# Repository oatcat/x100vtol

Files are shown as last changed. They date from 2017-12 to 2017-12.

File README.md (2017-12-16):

# x100vtol
a 100mm 4-rotor small drone using brushed motors, 2s li-po battery, 60mm prop.
One piece PCB-as-chassic, onboard mosfet motor driver, GY-86 as IMU.
Uses taulabs software. Hardware compatible as DISOVERY F4.

## To make one:
Order the PCB from a fab house, buy the necessary parts, solder the PCB.
Connect a S.BUS reciever to the port and fix the reciever on the PCB.
Flash taulabs firmware using ST-LINK, configure the UAV.

## BOM

Apart from the PCB BOM, you will need to secure the motors onto the PCB.
The motor mount I used is bought on taobao.com. If you can't get one you can change the PCB to suit your motor mount.

A small FPV Camera with built in VTX is needed if FPV is desireable.

A ~550mAh 2S battery is needed, and you will need a strap to fix the battery.
There are 2 slots on the PCB you can use to strap the battery.

For proper takeoff and landing you will need some kind of landing gear.
Just glue a small piece of plastic under each motor mount will be fine.

To flash the STM32 you will need ST-Link. Either a standalone one or a builtin on the Discovery board will be fine.

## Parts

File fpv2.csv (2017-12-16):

Qty | Value | Device | Package | Parts | Description | PROD_ID | VALUE
1 | 2PT_GND_TIE | 2PT_GND_TIE | 2PT_GND_TIE | SUPPLY1 | Dual Ground Supply
16 | 100n | C-EUC0603 | C0603 | C1, C2, C3, C4, C5, C6, C7, C8, C12, C13, C17, C19, C23, C24, C25, C26 | CAPACITOR, European symbol
2 | 20p | C-EUC0603 | C0603 | C21, C22 | CAPACITOR, European symbol
1 | 470pF | C-EUC0603 | C0603 | C20 | CAPACITOR, European symbol
2 | 2.2u | C-EUC1206 | C1206 | C14, C15 | CAPACITOR, European symbol
2 | 1u | CPOL-EUA/3216-18R | A/3216-18R | C10, C11 | POLARIZED CAPACITOR, European symbol
2 | 100u | CPOL-EUSMCB | SMC_B | C16, C18 | POLARIZED CAPACITOR, European symbol
1 | 8M | CRYSTALSMD-5X3.2-2PAD | CRYSTAL-SMD-5X3.2-2PAD | Y1 | Crystals (Generic)
4 | SS14 | DIODE-DO214AC | DO214AC | D5, D6, D7, D8 | DIODE
1 | GY-86 | GY-86 | GY-86 | MOD1
1 | FCM1608-0603 | INDUCTOR-0603-33NH | 603 | L1 | Inductors | NDUC-07874 | 33nH/±5%/500mA
1 | RST | JUMPER-SMT_2_NO_NO-SILK | SMT-JUMPER_2_NO_NO-SILK | S2 | Normally open jumper
1 | BLUE | LED0603 | LED-0603 | D4 | LED (Generic)
1 | GREEN | LED0603 | LED-0603 | D1 | LED (Generic)
1 | ORANGE | LED0603 | LED-0603 | D2 | LED (Generic)
1 | RED | LED0603 | LED-0603 | D3 | LED (Generic)
4 | IRLR7843 | MOSFET-NCH-FDD8780 | DPAK | Q1, Q2, Q3, Q4 | N-channel MOSFETs | TRANS-09984 | 35A/25V/8.5mΩ
4 | 5R | R-EU_R0603 | R0603 | R21, R22, R23, R24 | RESISTOR, European symbol
2 | 22R | R-EU_R0603 | R0603 | R8, R9 | RESISTOR, European symbol
1 | 47R | R-EU_R0603 | R0603 | R12 | RESISTOR, European symbol
1 | 220R | R-EU_R0603 | R0603 | R18 | RESISTOR, European symbol
2 | 510R | R-EU_R0603 | R0603 | R4, R13 | RESISTOR, European symbol
3 | 680R | R-EU_R0603 | R0603 | R5, R6, R7 | RESISTOR, European symbol
1 | 100k | R-EU_R0603 | R0603 | R3 | RESISTOR, European symbol
2 | 10k | R-EU_R0603 | R0603 | R11, R25 | RESISTOR, European symbol
3 | 4.7k | R-EU_R0603 | R0603 | R14, R15, R16 | RESISTOR, European symbol
1 | STM32F407VGT6 | STM32F4V_100PIN_GENERIC | LQFP100 | U1
1 | 5V | TPS-MODULE | 1X03 | MOD2
1 | MMBT3904 | TRANS_NPN-MMBT2222AL | SOT23-3 | Q5 | NPN transistor | TRANS-08049 | 600mA/40V
1 | USB | USB_MICRO-B_FEMALE-SMT | USB-B-MICRO-SMD | J21 | USB Type Micro-B Connector | CONN-11752
1 | MIC5219 3.3V | V_REG_MIC52193.3V | SOT23-5 | U4 | V_REG MIC5219 | VREG-09872 | MIC5219 3.3V

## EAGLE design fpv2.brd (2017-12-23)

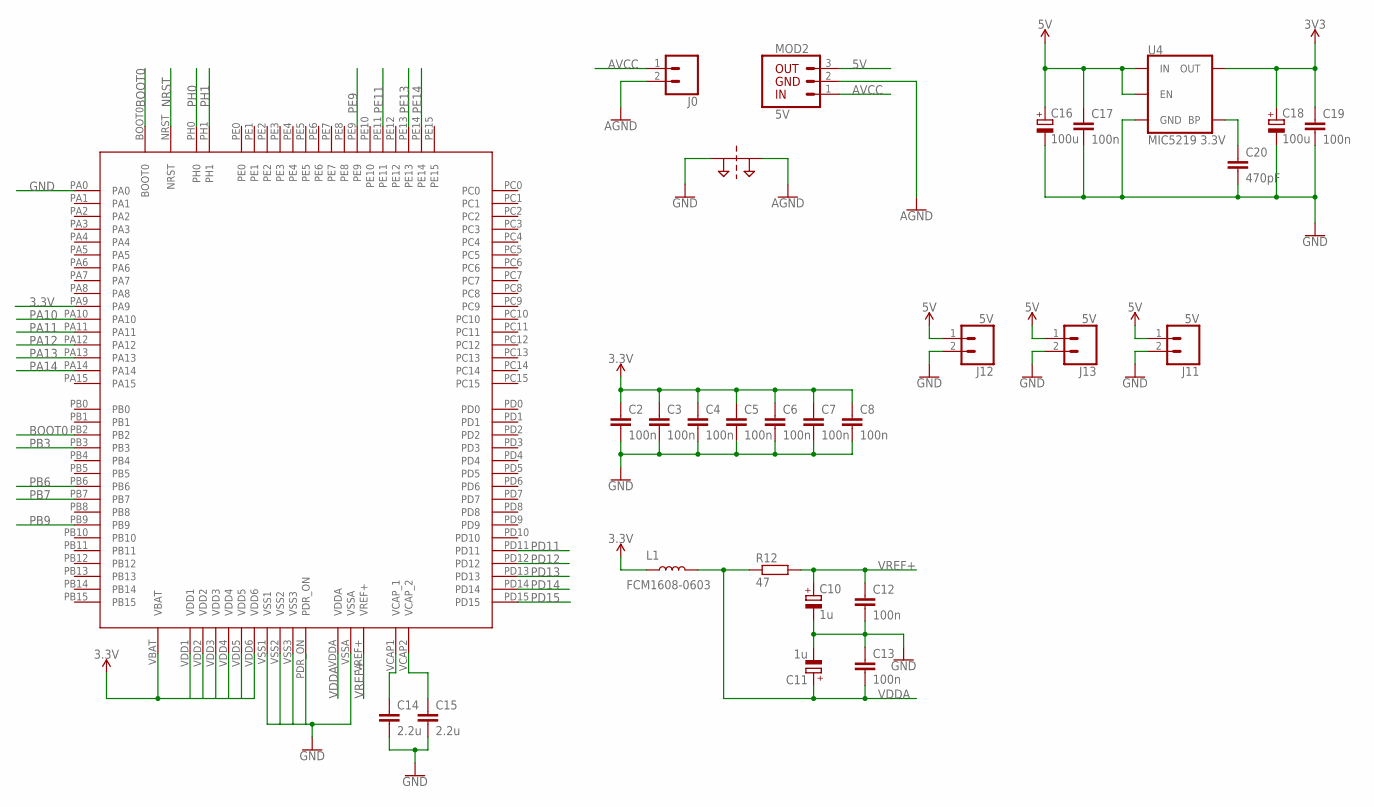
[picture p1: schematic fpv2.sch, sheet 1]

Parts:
C2, C3, C4, C5, C6, C7, C8, C12, C13, C17, C19: 100n; C0603
C10, C11: 1u; A/3216-18R
C14, C15: 2.2u; C1206
C16, C18: 100u; SMC_B
C20: 470pF; C0603
J0: CONN_02LOCK_LONGPADS; 1X02_LOCK_LONGPADS
J11, J12, J13: 5V; SMD
L1: FCM1608-0603; 0603
MOD2: 5V; 1X03
R12: 47; R0603
SUPPLY1: 2PT_GND_TIE
U1: STM32F407VGT6; LQFP100
U4: MIC5219 3.3V; SOT23-5

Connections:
3.3V: C2.1, C3.1, C4.1, C5.1, C6.1, C7.1, C8.1, C18.+, C19.1, L1.1, U1.PA9, U1.VBAT, U1.VDD1, U1.VDD2, U1.VDD3, U1.VDD4, U1.VDD5, U1.VDD6, U4.5 (OUT); also elsewhere on the board
5V: C16.+, C17.1, J11.1, J12.1, J13.1, MOD2.3, U4.1 (IN), U4.3 (EN); also elsewhere on the board
AGND: J0.2, MOD2.2, SUPPLY1.P$2; also elsewhere on the board
AVCC: J0.1, MOD2.1; also elsewhere on the board
BOOT0: U1.BOOT0, U1.PB2; also elsewhere on the board
GND: C2.2, C3.2, C4.2, C5.2, C6.2, C7.2, C8.2, C10.-, C11.-, C12.2, C13.1, C14.2, C15.2, C16.-, C17.2, C18.-, C19.2, C20.2, J11.2, J12.2, J13.2, SUPPLY1.P$1, U1.PA0, U1.PDR_ON, U1.VSS1, U1.VSS2, U1.VSS3, U1.VSSA, U4.2 (GND); also elsewhere on the board
unnamed: C14.1, U1.VCAP1 (VCAP_1)
unnamed: C15.1, U1.VCAP2 (VCAP_2)
unnamed: C20.1, U4.4 (BP)
NRST: U1.NRST; also elsewhere on the board
PA10: U1.PA10
PA11: U1.PA11; also elsewhere on the board
PA12: U1.PA12; also elsewhere on the board
PA13: U1.PA13; also elsewhere on the board
PA14: U1.PA14; also elsewhere on the board
PB3: U1.PB3; also elsewhere on the board
PB6: U1.PB6; also elsewhere on the board
PB7: U1.PB7; also elsewhere on the board
PB9: U1.PB9; also elsewhere on the board
PD11: U1.PD11; also elsewhere on the board
PD12: U1.PD12; also elsewhere on the board
PD13: U1.PD13; also elsewhere on the board
PD14: U1.PD14; also elsewhere on the board
PD15: U1.PD15; also elsewhere on the board
PE9: U1.PE9; also elsewhere on the board
PE11: U1.PE11; also elsewhere on the board
PE13: U1.PE13; also elsewhere on the board
PE14: U1.PE14; also elsewhere on the board
PH0: U1.PH0; also elsewhere on the board
PH1: U1.PH1; also elsewhere on the board
VDDA: C11.+, C13.2, L1.2, R12.1, U1.VDDA
VREF+: C10.+, C12.1, R12.2, U1.VREF+

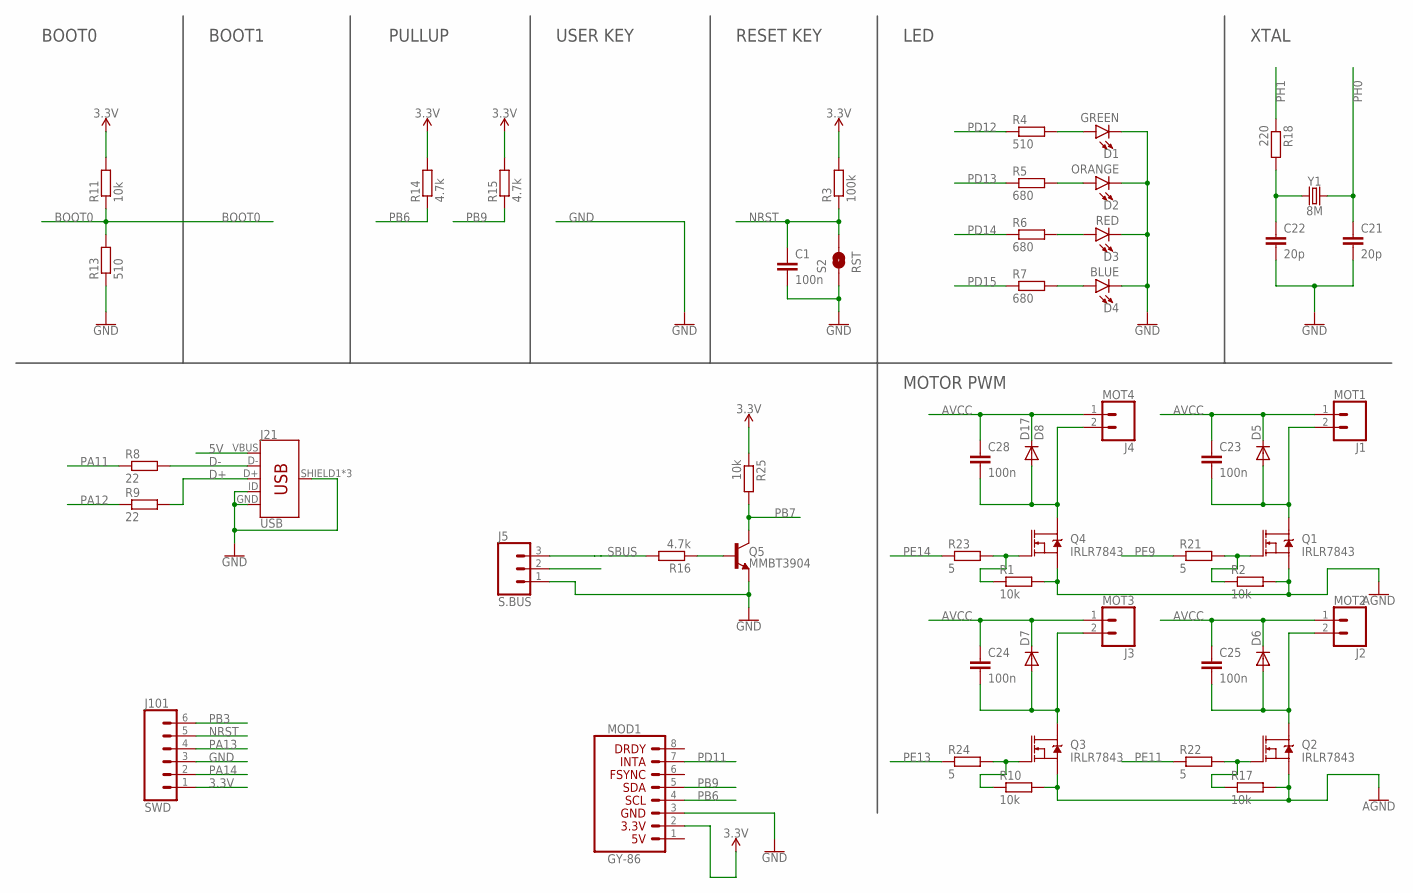
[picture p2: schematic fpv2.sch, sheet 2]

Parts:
C1, C23, C24, C25, C28: 100n; C0603
C21, C22: 20p; C0603
D1: GREEN; LED-0603
D2: ORANGE; LED-0603
D3: RED; LED-0603
D4: BLUE; LED-0603
D5, D6, D7: DIODE-DO214AC; DO214AC
D17: D8; DO214AC
J1: MOT1; 1X02_LOCK_LONGPADS
J2: MOT2; 1X02_LOCK_LONGPADS
J3: MOT3; 1X02_LOCK_LONGPADS
J4: MOT4; 1X02_LOCK_LONGPADS
J5: S.BUS; 1X03
J21: USB; USB-B-MICRO-SMD
J101: SWD; 1X06-SMD-FEMALE
MOD1: GY-86
Q1, Q2, Q3, Q4: IRLR7843; DPAK
Q5: MMBT3904; SOT23-3
R1, R2, R10, R11, R17, R25: 10k; R0603
R3: 100k; R0603
R4, R13: 510; R0603
R5, R6, R7: 680; R0603
R8, R9: 22; R0603
R14, R15, R16: 4.7k; R0603
R18: 220; R0603
R21, R22, R23, R24: 5; R0603
S2: RST; SMT-JUMPER_2_NO_NO-SILK
Y1: 8M; CRYSTAL-SMD-5X3.2-2PAD

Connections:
3.3V: J101.1, MOD1.2 (3.3V), R3.2, R11.2, R14.2, R15.2, R25.1; also elsewhere on the board
5V: J5.2, J21.VBUS; also elsewhere on the board
AGND: Q1.3 (S), Q2.3 (S), Q3.3 (S), Q4.3 (S), R1.2, R2.2, R10.2, R17.2; also elsewhere on the board
AVCC: C23.1, C24.1, C25.1, C28.1, D5.C, D6.C, D7.C, D17.C, J1.1, J2.1, J3.1, J4.1; also elsewhere on the board
BOOT0: R11.1, R13.2; also elsewhere on the board
D+: J21.D+, R9.2
D-: J21.D-, R8.2
GND: C1.2, C21.2, C22.2, D1.C, D2.C, D3.C, D4.C, J5.1, J21.GND, J21.ID, J21.SHIELD1 (SHIELD), J21.SHIELD2 (SHIELD), J21.SHIELD3 (SHIELD), J101.3, MOD1.3 (GND), Q5.2 (E), R13.1, S2.1; also elsewhere on the board
unnamed: C23.2, D5.A, J1.2, Q1.4 (D)
unnamed: D1.A, R4.2
unnamed: D2.A, R5.2
unnamed: D3.A, R6.2
unnamed: D4.A, R7.2
unnamed: C25.2, D6.A, J2.2, Q2.4 (D)
unnamed: Q4.1 (G), R1.1, R23.2
unnamed: Q1.1 (G), R2.1, R21.2
unnamed: C22.1, R18.2, Y1.P$1 (1)
unnamed: Q3.1 (G), R10.1, R24.2
unnamed: C28.2, D17.A, J4.2, Q4.4 (D)
unnamed: Q2.1 (G), R17.1, R22.2
unnamed: Q5.1 (B), R16.1
unnamed: C24.2, D7.A, J3.2, Q3.4 (D)
NRST: C1.1, J101.5, R3.1, S2.2; also elsewhere on the board
PA11: R8.1; also elsewhere on the board
PA12: R9.1; also elsewhere on the board
PA13: J101.4; also elsewhere on the board
PA14: J101.2; also elsewhere on the board
PB3: J101.6; also elsewhere on the board
PB6: MOD1.4 (SCL), R14.1; also elsewhere on the board
PB7: Q5.3 (C), R25.2; also elsewhere on the board
PB9: MOD1.5 (SDA), R15.1; also elsewhere on the board
PD11: MOD1.7 (INTA); also elsewhere on the board
PD12: R4.1; also elsewhere on the board
PD13: R5.1; also elsewhere on the board
PD14: R6.1; also elsewhere on the board
PD15: R7.1; also elsewhere on the board
PE9: R21.1; also elsewhere on the board
PE11: R22.1; also elsewhere on the board
PE13: R24.1; also elsewhere on the board
PE14: R23.1; also elsewhere on the board
PH0: C21.1, Y1.P$2 (2); also elsewhere on the board
PH1: R18.1; also elsewhere on the board
SBUS: J5.3, R16.2

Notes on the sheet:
BOOT0
BOOT1
PULLUP
USER KEY
RESET KEY
LED
XTAL
MOTOR PWM

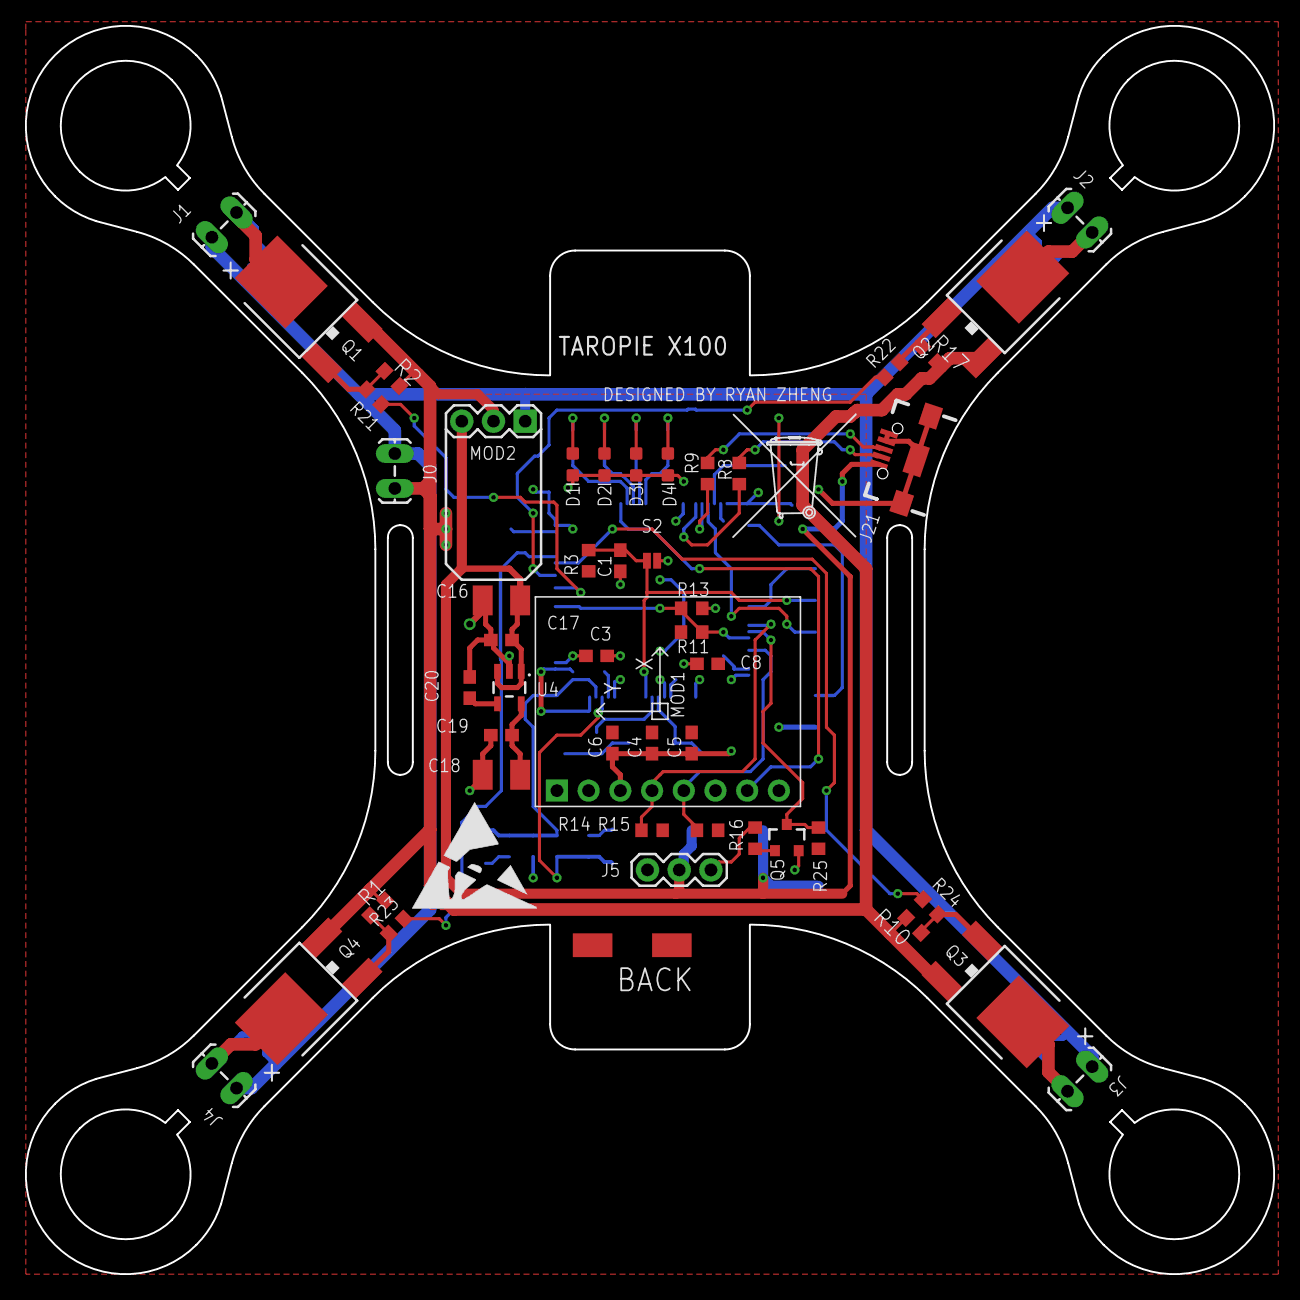
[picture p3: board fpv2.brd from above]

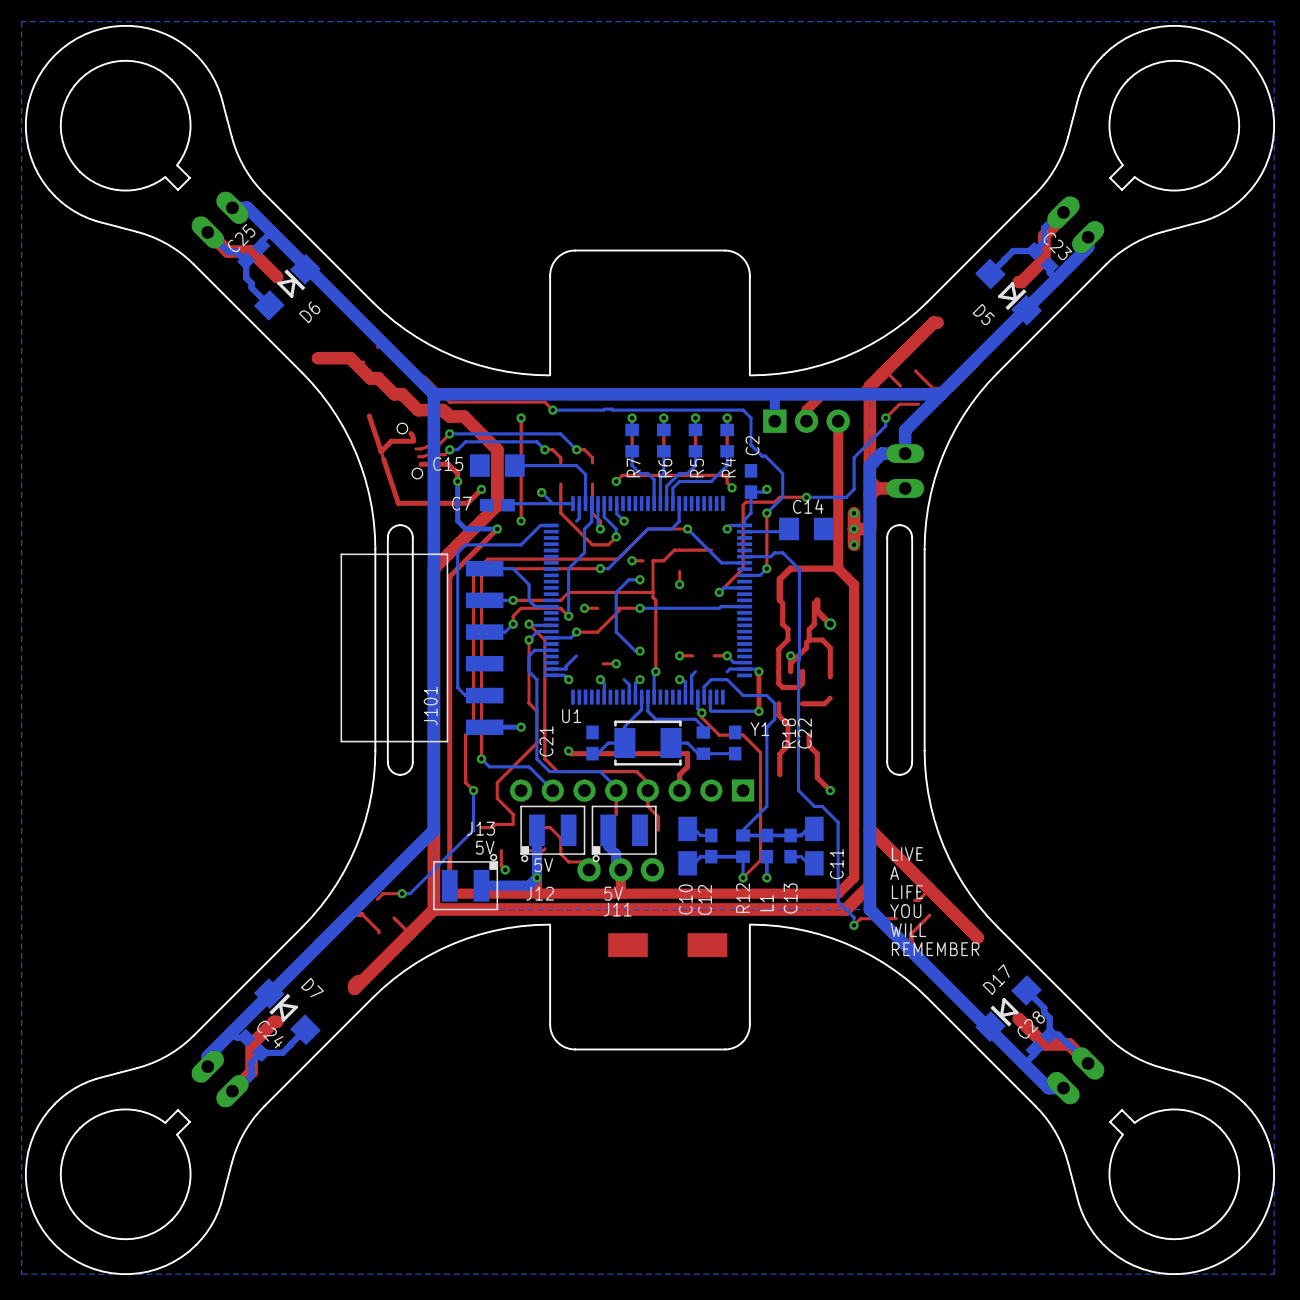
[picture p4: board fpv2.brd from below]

Board: 2 copper layers, 100.0 x 100.0 mm, 82 parts (31 on the bottom side), 48 nets.

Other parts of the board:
U$1: TONNE_10.00
U$2: ESD_10.00

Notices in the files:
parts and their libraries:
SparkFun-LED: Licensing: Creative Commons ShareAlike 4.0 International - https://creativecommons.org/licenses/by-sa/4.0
